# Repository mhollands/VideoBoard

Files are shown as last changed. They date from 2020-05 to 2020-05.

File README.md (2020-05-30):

# VideoBoard
Repo to hold files for the video board which was a prototype for the HP2VGA project

# Known Issues
Vsync and Hsync are swapped. C23 and C32 are unnecessary. Solution, use C23 and C32 footprints to swap the Vsync and Hsync inputs.





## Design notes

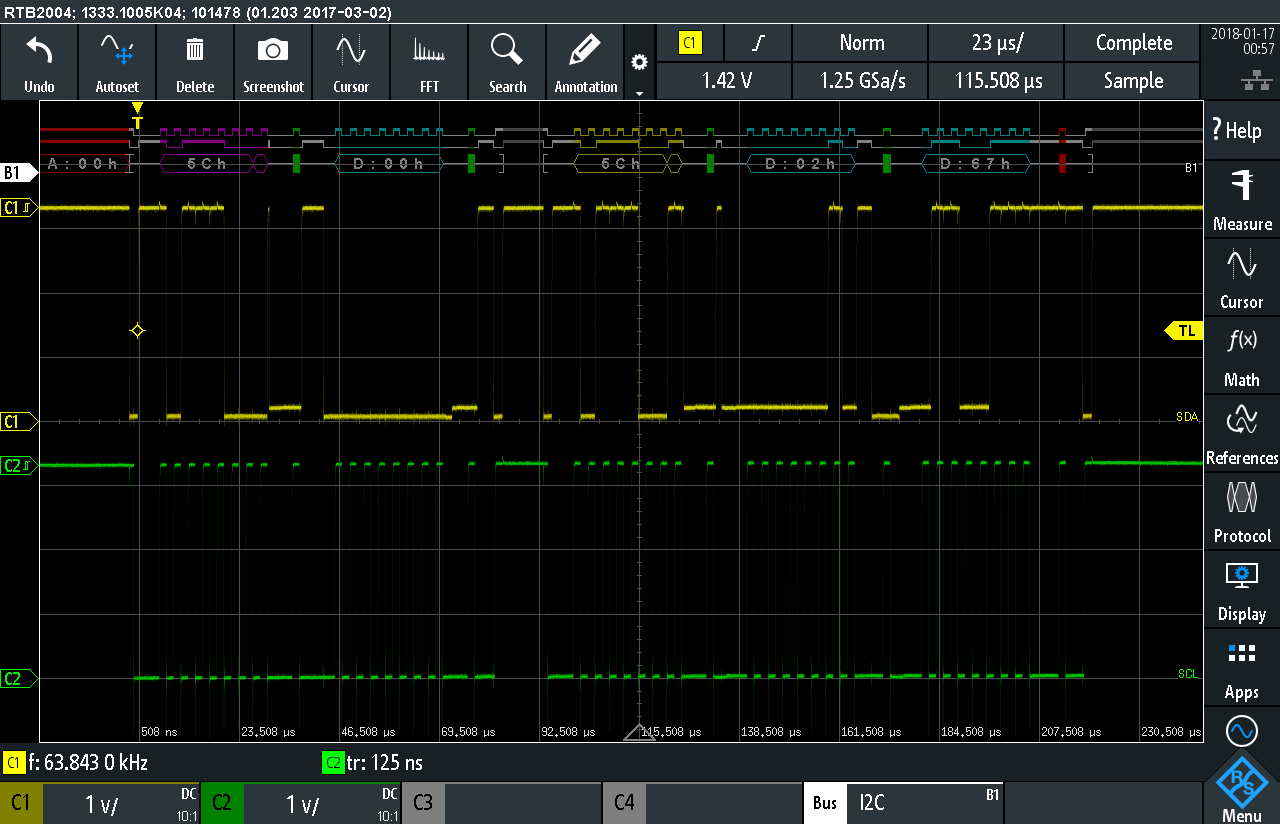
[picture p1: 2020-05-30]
Pictures/I2C.PNG

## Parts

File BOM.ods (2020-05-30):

Ref | Description | #Needed | Digikey#
CON1 | AVRISP Header Shrouded | 1 | 609-5122-ND | 2
IC1 | ATTiny87 | 1 | ATTINY87-SU-ND | 0
C2, C3, C36-C51, C21, C23, C32, C35 | 0603 0.1uF | 22 | - | 0
R8 | 0603 4k7 | 1 | - | 0
R6, R7, R10-R13, R15 | 0603 2k2 | 7 | 311-2.20KHRCT-ND | 100
P1 | 02x10 Header Shrouded | 1 | ED10524-ND | 1
L1-L6 | 0603 Ferrite 1A, 200 mOhm | 7 | MH1608-601YCT-ND | 10
R3 | 0603 75R | 1 | P75.0HCT-ND or 311-2667-1-ND | 10
R9 | 0603 330R | 1 | - | 0
C12, C26 | 0603 1nF | 2 | - | 0
U3 | Schmitt Trigger SOT-23-6 | 1 | 296-13012-1-ND | 2
C18-C20, C22, C25, C27-C31, C34 | 0603 10nF | 11 | 1276-1921-1-ND | 100
R14 | 0603 1k5 | 1 | - | 0
C17 | 0603 4.7nF | 1 | 1276-1098-1-ND | 10
P6, P7 | 02x06 Right Angle Header | 2 | S2111EC-06-ND | 2
C1, C4, C5 | 10uF, 2mm pitch, 5mm diameter | 3 | 1189-2322-ND | 3
U1 | 3V3 LDO, TO-220, Low thermal resistance | 1 | 497-1491-5-ND | 2
U2 | Adjustable LDO, DPAK | 1 | NCP1117DTAGOS-ND | 2
R2 | 0603 1k, 1% | 1 | - | 0
R1 | 0603 520R, 1% | 1 | 311-523HRCT-ND | 10
C6, C7, C10, C11, C15 | 0603 22uF | 5 | 1276-1193-1-ND | 10
C8, C9, C13, C14, C16 | 0603 1uF | 5 | - | 0
Heatsink | For U1 | 1 | A10761-ND | 2
U4 | TVP7002 | 1 | 296-22891-ND | 2

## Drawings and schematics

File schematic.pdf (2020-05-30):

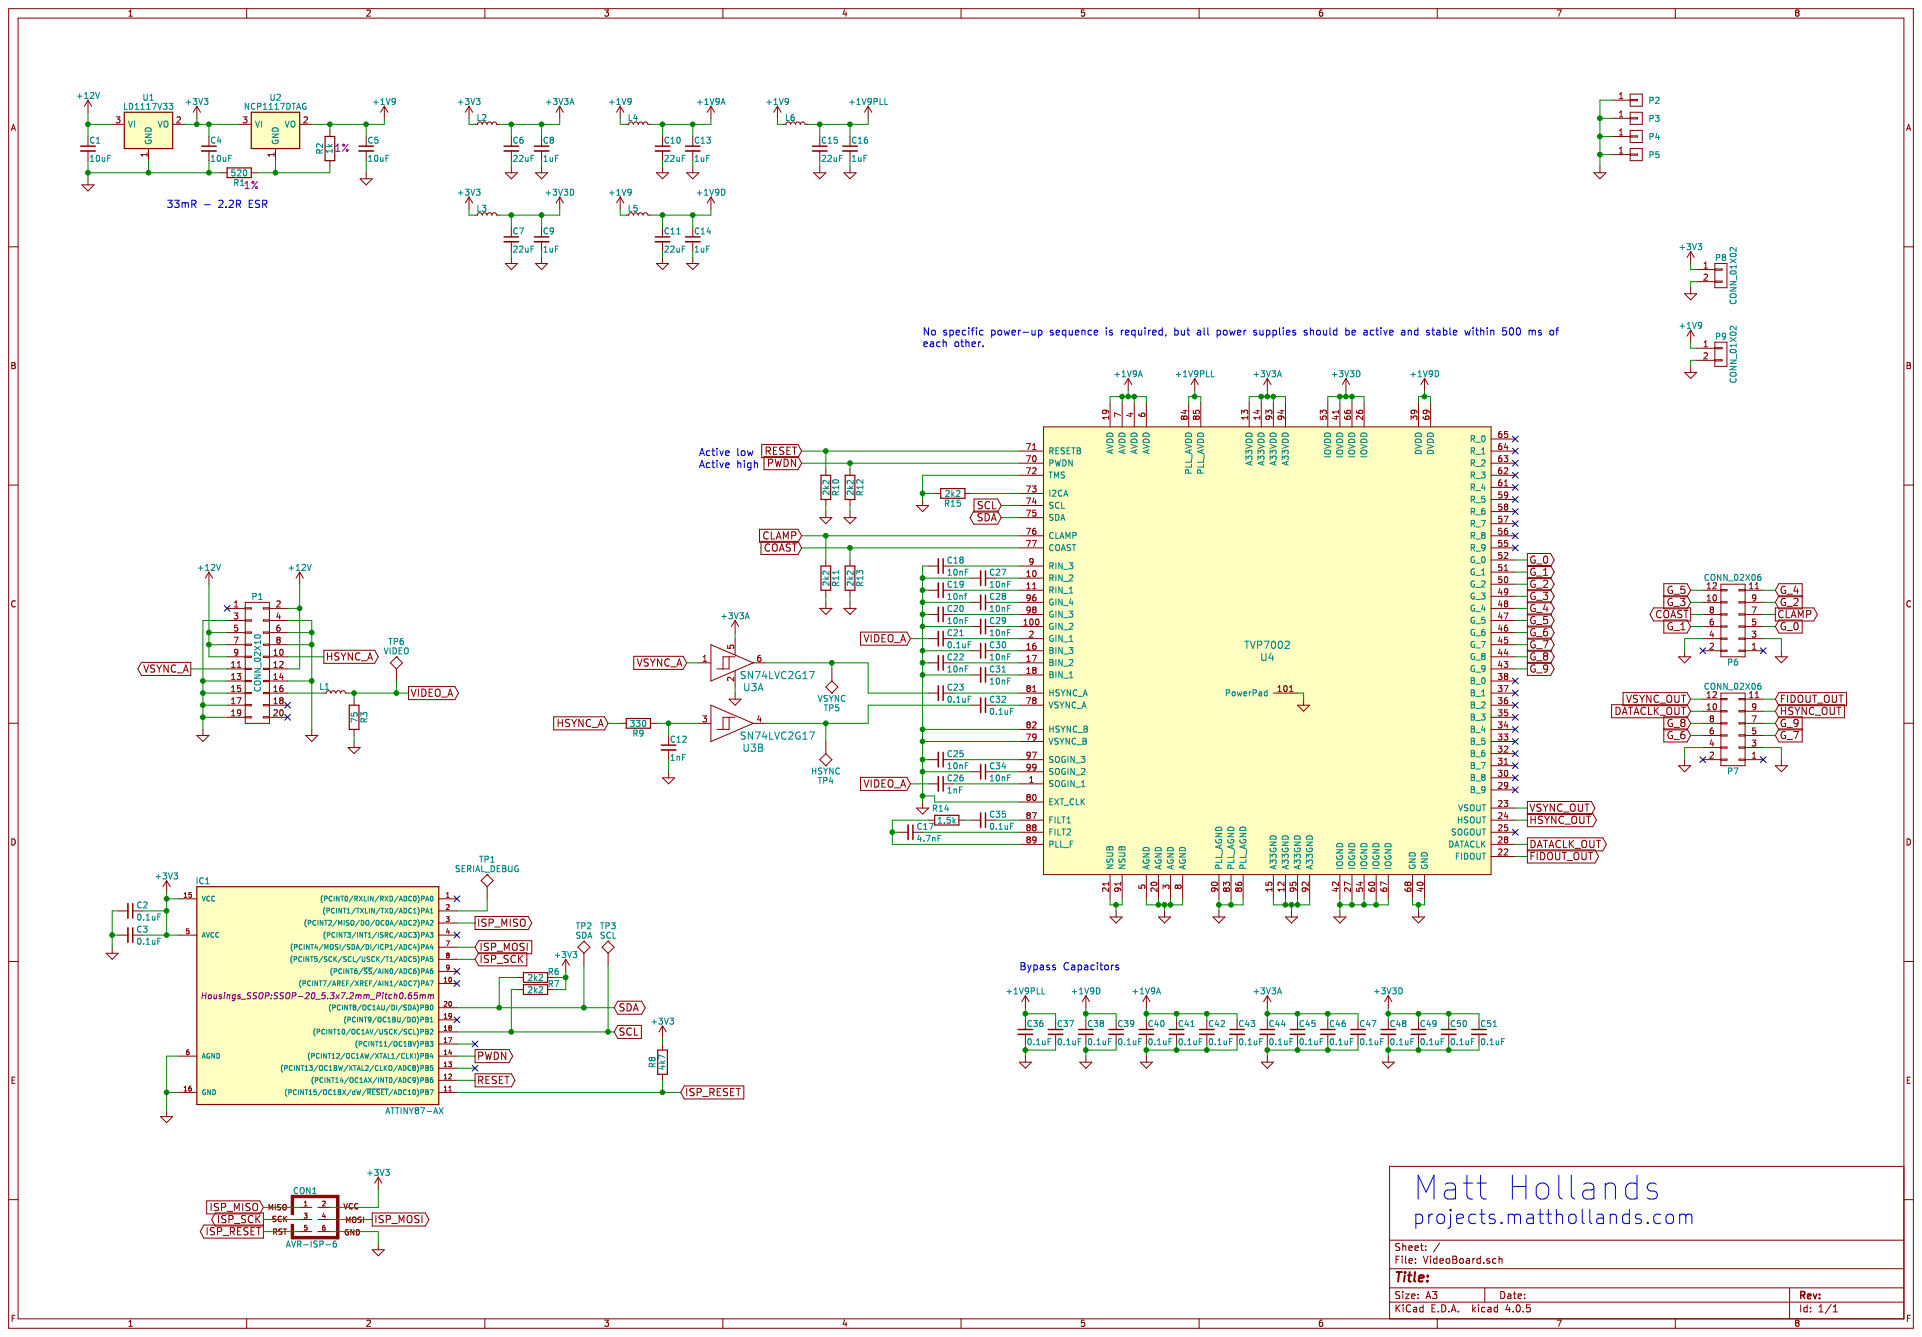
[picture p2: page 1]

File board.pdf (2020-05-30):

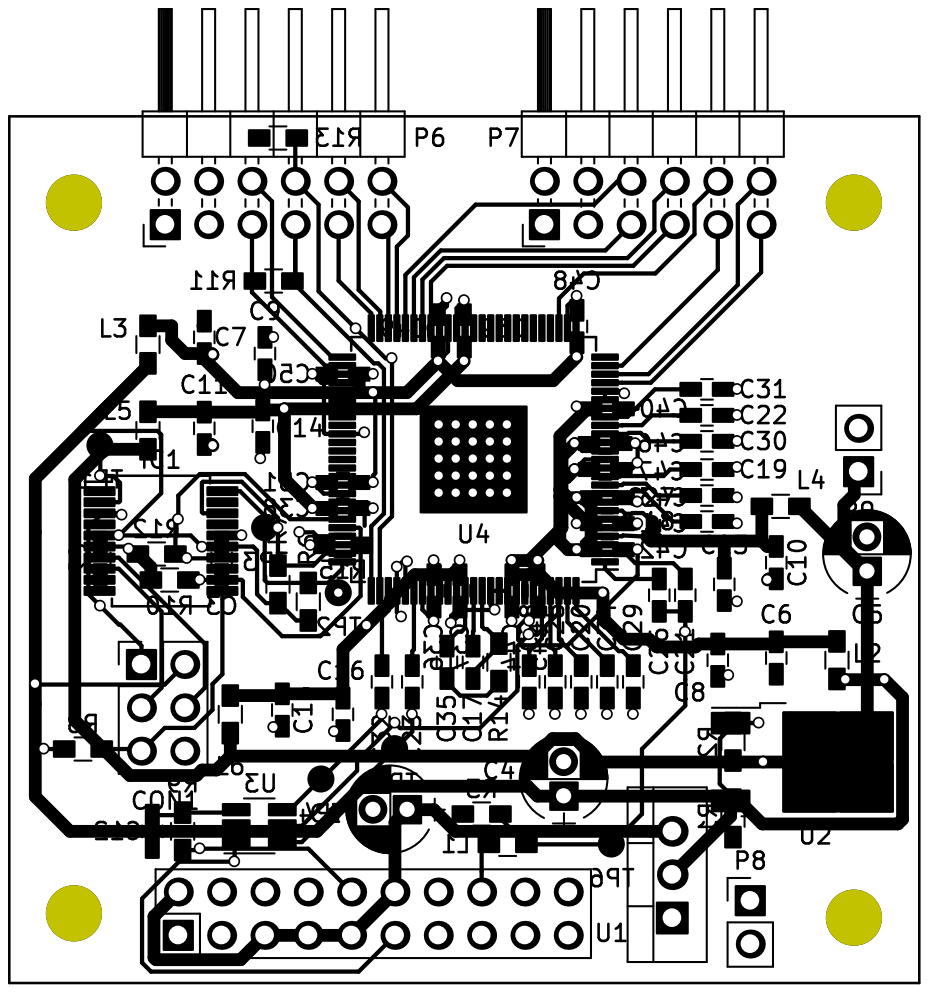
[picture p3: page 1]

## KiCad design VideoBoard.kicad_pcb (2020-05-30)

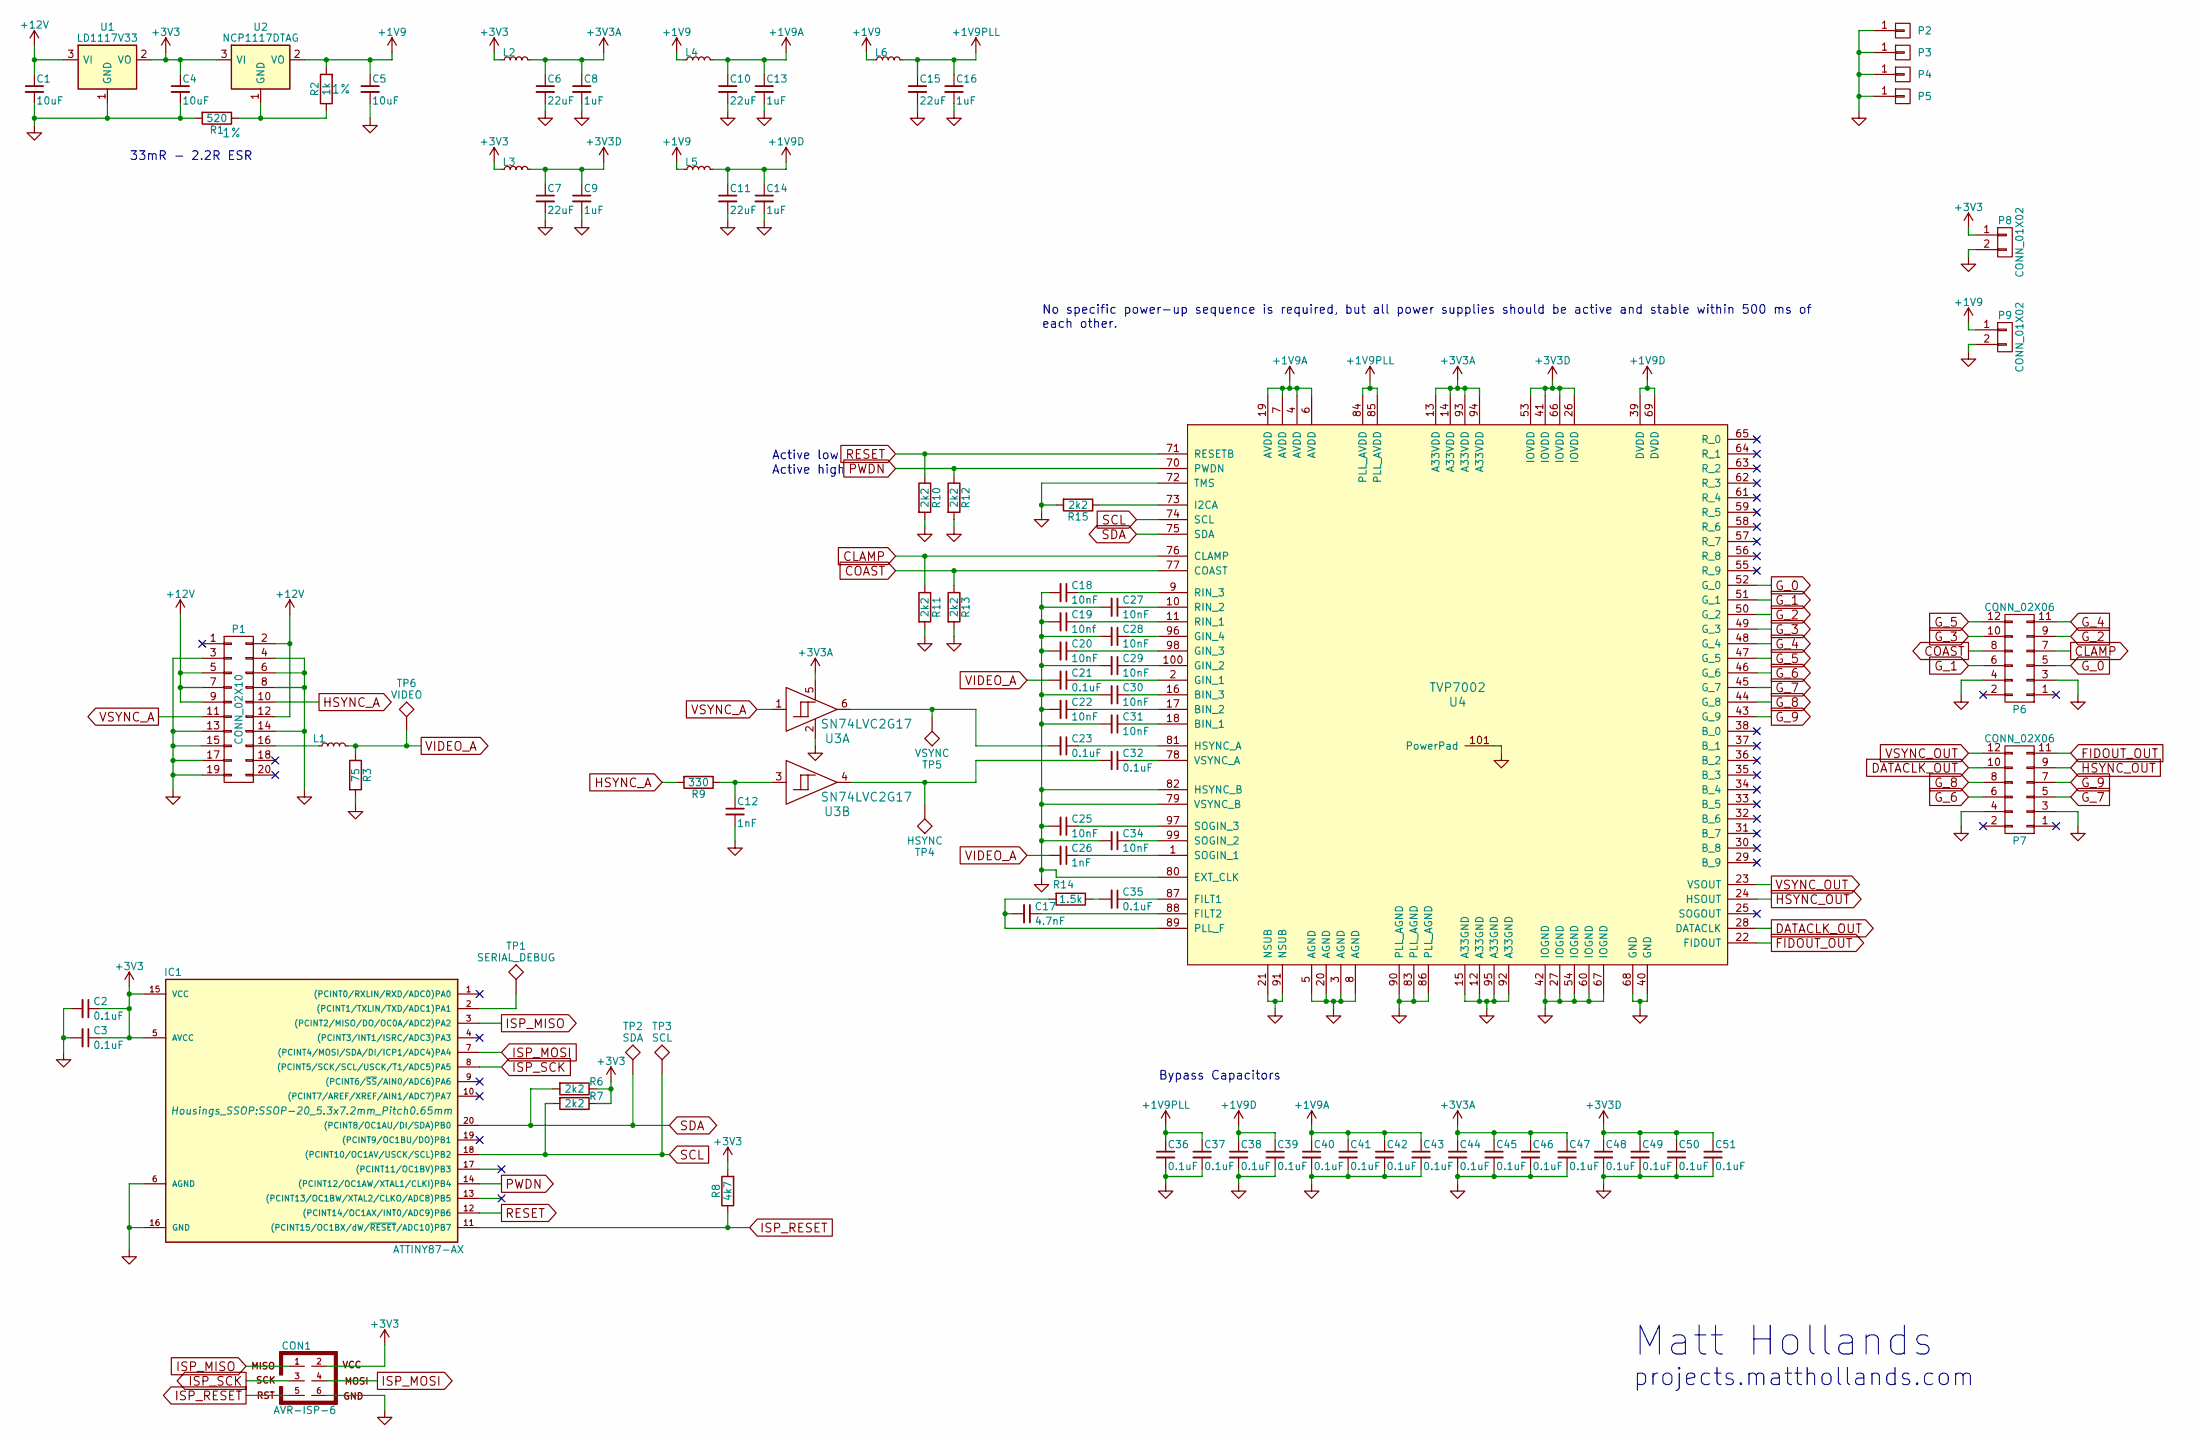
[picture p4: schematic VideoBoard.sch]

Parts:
C1, C4, C5: 10uF; CP_Radial_D5.0mm_P2.00mm; Digikey# 1189-2322-ND
C2, C3, C21, C23, C32, C35, C36, C37, C38, C39, C40, C41, C42, C43, C44, C45, C46, C47, C48, C49, C50, C51: 0.1uF; C_0603_HandSoldering
C6, C7, C10, C11, C15: 22uF; C_0603_HandSoldering
C8, C9, C13, C14, C16: 1uF; C_0603_HandSoldering
C12, C26: 1nF; C_0603_HandSoldering
C17: 4.7nF; C_0603_HandSoldering
C18, C20, C22, C25, C27, C28, C29, C30, C31, C34: 10nF; C_0603_HandSoldering
C19: 10nf; C_0603_HandSoldering
CON1: AVR-ISP-6; Pin_Header_Straight_2x03_Pitch2.54mm; Digikey# 609-5122-ND
IC1: ATTINY87-AX; SSOP-20_5.3x7.2mm_Pitch0.65mm
L1: L_Small; R_0603_HandSoldering
L2, L3, L4, L5, L6: L_Small; R_0603_HandSoldering; Digikey# MH1608-601YCT-ND
P1: CONN_02X10; Pin_Header_Straight_2x10_Pitch2.54mm
P2, P3, P4, P5: CONN_01X01; MountingHole_3.2mm_M3
P6, P7: CONN_02X06; Pin_Header_Angled_2x06_Pitch2.54mm
P8, P9: CONN_01X02; Pin_Header_Straight_1x02_Pitch2.54mm
R1: 520; R_0603_HandSoldering; Tolerance 1%
R2: 1k; R_0603_HandSoldering; Tolerance 1%
R3: 75; R_0603_HandSoldering
R6, R7, R10, R11, R12, R13, R15: 2k2; R_0603_HandSoldering
R8: 4k7; R_0603_HandSoldering
R9: 330; R_0603_HandSoldering
R14: 1.5k; R_0603_HandSoldering
TP1: SERIAL_DEBUG; Measurement_Point_Round-SMD-Pad_Small
TP2: SDA; Measurement_Point_Round-SMD-Pad_Small
TP3: SCL; Measurement_Point_Round-SMD-Pad_Small
TP4: HSYNC; Measurement_Point_Round-SMD-Pad_Small
TP5: VSYNC; Measurement_Point_Round-SMD-Pad_Small
TP6: VIDEO; Measurement_Point_Round-SMD-Pad_Small
U1: LD1117V33; TO-220_Vertical; Digikey# 497-1491-5-ND
U2: NCP1117DTAG; TO-252-2
U3: SN74LVC2G17; SOT-23-6_Handsoldering
U4: TVP7002; TQFP-100_14x14mm_Pitch0.5mm-PowerPad; Digikey# 296-22891-ND

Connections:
+1V9: C5.1, L4.1, L5.1, L6.1, P9.1, R2.2, U2.2 (VO)
+1V9A: C10.1, C13.1, C40.1, C41.1, C42.1, C43.1, L4.2, U4.4 (AVDD), U4.6 (AVDD), U4.7 (AVDD), U4.19 (AVDD)
+1V9D: C11.1, C14.1, C38.1, C39.1, L5.2, U4.39 (DVDD), U4.69 (DVDD)
+1V9PLL: C15.1, C16.1, C36.1, C37.1, L6.2, U4.84 (PLL_AVDD), U4.85 (PLL_AVDD)
+3V3: C2.1, C3.1, C4.1, CON1.2, IC1.5 (AVCC), IC1.15 (VCC), L2.1, L3.1, P8.1, R6.1, R7.1, R8.2, U1.2 (VO), U2.3 (VI)
+3V3A: C6.1, C8.1, C44.1, C45.1, C46.1, C47.1, L2.2, U3.5, U4.13 (A33VDD), U4.14 (A33VDD), U4.93 (A33VDD), U4.94 (A33VDD)
+3V3D: C7.1, C9.1, C48.1, C49.1, C50.1, C51.1, L3.2, U4.26 (IOVDD), U4.41 (IOVDD), U4.53 (IOVDD), U4.66 (IOVDD)
+12V: C1.1, P1.2, P1.5, P1.7, P1.9, P1.12, U1.3 (VI)
CLAMP: P6.7, R11.1, U4.76 (CLAMP)
COAST: P6.8, R13.1, U4.77 (COAST)
DATACLK_OUT: P7.10, U4.28 (DATACLK)
FIDOUT_OUT: P7.11, U4.22 (FIDOUT)
GND: C1.2, C2.2, C3.2, C4.2, C5.2, C6.2, C7.2, C8.2, C9.2, C10.2, C11.2, C12.2, C13.2, C14.2, C15.2, C16.2, C18.2, C19.2, C20.2, C22.2, C25.2, C27.2, C28.2, C29.2, C30.2, C31.2, C34.2, C36.2, C37.2, C38.2, C39.2, C40.2, C41.2, C42.2, C43.2, C44.2, C45.2, C46.2, C47.2, C48.2, C49.2, C50.2, C51.2, CON1.6, IC1.6 (AGND), IC1.16 (GND), P1.3, P1.4, P1.6, P1.8, P1.13, P1.14, P1.15, P1.17, P1.19, P2.1, P3.1, P4.1, P5.1, P6.3, P6.4, P7.3, P7.4, P8.2, P9.2, R1.2, R3.2, R10.2, R11.2, R12.2, R13.2, R15.2, U1.1 (GND), U3.2, U4.3 (AGND), U4.5 (AGND), U4.8 (AGND), U4.12 (A33GND), U4.15 (A33GND), U4.20 (AGND), U4.21 (NSUB), U4.27 (IOGND), U4.40 (GND), U4.42 (IOGND), U4.54 (IOGND), U4.60 (IOGND), U4.67 (IOGND), U4.68 (GND), U4.72 (TMS), U4.79 (VSYNC_B), U4.80 (EXT_CLK), U4.82 (HSYNC_B), U4.83 (PLL_AGND), U4.86 (PLL_AGND), U4.90 (PLL_AGND), U4.91 (NSUB), U4.92 (A33GND), U4.95 (A33GND), U4.101 (PowerPad)
G_0: P6.5, U4.52 (G_0)
G_1: P6.6, U4.51 (G_1)
G_2: P6.9, U4.50 (G_2)
G_3: P6.10, U4.49 (G_3)
G_4: P6.11, U4.48 (G_4)
G_5: P6.12, U4.47 (G_5)
G_6: P7.6, U4.46 (G_6)
G_7: P7.5, U4.45 (G_7)
G_8: P7.8, U4.44 (G_8)
G_9: P7.7, U4.43 (G_9)
HSYNC_A: P1.10, R9.2
HSYNC_OUT: P7.9, U4.24 (HSOUT)
ISP_MISO: CON1.1, IC1.3 ((PCINT2/MISO/DO/OC0A/ADC2)PA2)
ISP_MOSI: CON1.4, IC1.7 ((PCINT4/MOSI/SDA/DI/ICP1/ADC4)PA4)
ISP_RESET: CON1.5, IC1.11 ((PCINT15/OC1BX/dW/~RESET~/ADC10)PB7), R8.1
ISP_SCK: CON1.3, IC1.8 ((PCINT5/SCK/SCL/USCK/T1/ADC5)PA5)
unnamed: C12.1, R9.1, U3.3
unnamed: C17.1, U4.88 (FILT2)
unnamed: C17.2, R14.2, U4.89 (PLL_F)
unnamed: C18.1, U4.9 (RIN_3)
unnamed: C19.1, U4.11 (RIN_1)
unnamed: C20.1, U4.98 (GIN_3)
unnamed: C21.1, U4.2 (GIN_1)
unnamed: C22.1, U4.17 (BIN_2)
unnamed: C23.1, U4.81 (HSYNC_A)
unnamed: C23.2, TP5.1, U3.6
unnamed: C25.1, U4.97 (SOGIN_3)
unnamed: C26.1, U4.1 (SOGIN_1)
unnamed: C27.1, U4.10 (RIN_2)
unnamed: C28.1, U4.96 (GIN_4)
unnamed: C29.1, U4.100 (GIN_2)
unnamed: C30.1, U4.16 (BIN_3)
unnamed: C31.1, U4.18 (BIN_1)
unnamed: C32.1, U4.78 (VSYNC_A)
unnamed: C32.2, TP4.1, U3.4
unnamed: C34.1, U4.99 (SOGIN_2)
unnamed: C35.1, U4.87 (FILT1)
unnamed: C35.2, R14.1
unnamed: IC1.2 ((PCINT1/TXLIN/TXD/ADC1)PA1), TP1.1
unnamed: L1.1, P1.16
unnamed: R1.1, R2.1, U2.1 (GND)
unnamed: R15.1, U4.73 (I2CA)
PWDN: IC1.14 ((PCINT12/OC1AW/XTAL1/CLKI)PB4), R12.1, U4.70 (PWDN)
RESET: IC1.12 ((PCINT14/OC1AX/INT0/ADC9)PB6), R10.1, U4.71 (RESETB)
SCL: IC1.18 ((PCINT10/OC1AV/USCK/SCL)PB2), R7.2, TP3.1, U4.74 (SCL)
SDA: IC1.20 ((PCINT8/OC1AU/DI/SDA)PB0), R6.2, TP2.1, U4.75 (SDA)
VIDEO_A: C21.2, C26.2, L1.2, R3.1, TP6.1
VSYNC_A: P1.11, U3.1
VSYNC_OUT: P7.12, U4.23 (VSOUT)

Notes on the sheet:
No specific power-up sequence is required, but all power supplies should be active and stable within 500 ms of each other.
Bypass Capacitors
Active low
Active high
33mR - 2.2R ESR
Matt Hollands
projects.matthollands.com

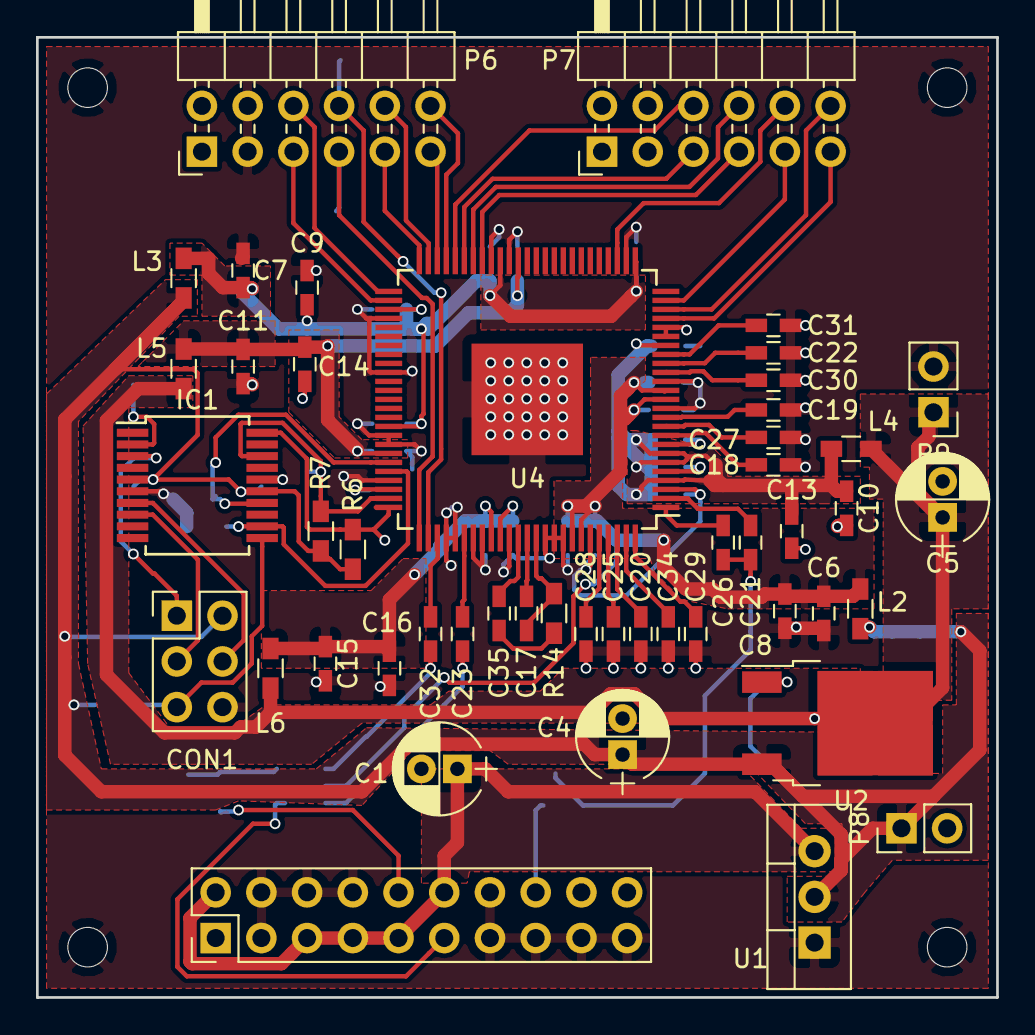
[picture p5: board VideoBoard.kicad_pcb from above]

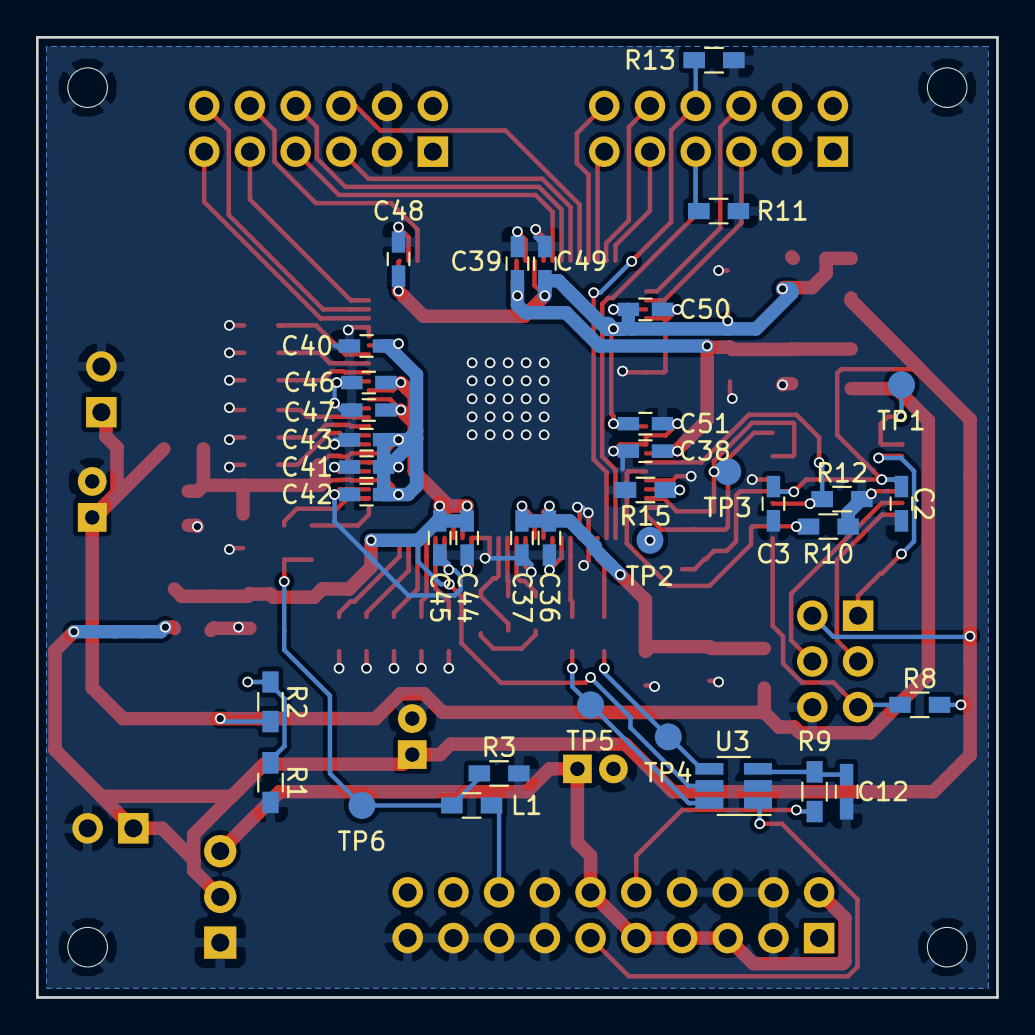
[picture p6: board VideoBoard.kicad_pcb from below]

Board: 2 copper layers, 53.3 x 53.3 mm, 89 parts (37 on the bottom side), 62 nets.

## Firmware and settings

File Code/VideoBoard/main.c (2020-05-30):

/*
 * VideoBoard.c
 *
 * Created: 29/11/2017 21:52:00
 * Author : Matt
 */ 

#define F_CPU 8000000U

#include <avr/io.h>
#include <util/delay.h>
//#include "usi_i2c_master.h"
#include <avr/interrupt.h>
#include "usiTwiMaster.h"

#define TVP_W 0xB8
#define TVP_R 0xB9
#define TVP_CHIP_REV 0x00
#define TVP_HPLL_DIV_MSB 0x01
#define TVP_HPLL_DIV_LSB 0x02
#define TVP_HPLL_CTRL 0x03
#define TVP_HPLL_PHASE 0x04
#define TVP_CLAMP_START 0x05
#define TVP_CLAMP_WIDTH 0x06
#define TVP_GREEN_FINE_OFFSET 0x0C
#define TVP_SYNC_CTRL1 0x0E
#define TVP_HPLL_PRECOAST 0x12
#define TVP_SYNC_DETECT_STATUS 0x14
#define TVP_MISC_CTRL2 0x17
#define TVP_MISC_CTRL3 0x18
#define TVP_MISC_CTRL4 0x22
#define TVP_ALC_EN 0x26
#define TVP_POWER_CTRL 0x2B
#define TVP_SYNC_BYPASS 0x36
#define TVP_LPFl_STATUS 0x37
#define TVP_LPFh_STATUS 0x38
#define TVP_CPLl_STATUS 0x39
#define TVP_CPLh_STATUS 0x3A
#define TVP_HSYNC_WIDTH 0x3B
#define TVP_VSYNC_WIDTH 0x3C
#define TVP_1ST_COEF 0x4A

//800 pixels per line. hsync is 64. FP is 136. BP is 24.
//417 lines per frame. vsync is 3. FP is 25. BP is 11.
uint8_t reg_setting[66] = {	TVP_W, 0x00, 0x00, 0x64, 0x00, 0x20, 0x01, 0x06, 0x10, 0x51, 0x00, 0x90, 0x00, 0x40, 0x78, 0x80, 0x52, 0x2E, 0x5D, 0x20, 0x03, 0x03, 0x00, 0x04, 0x11, 
							0x12, 0x00, 0x00, 0xC2, 0x77, 0x07, 0x00, 0x10, 0x10, 0x10, 0x00, 0x06, 0x00, 0x00, 0x00, 0x00, 0x00, 0x53, 0x08, 0x07, 0x85, 0x50, 0x00, 
							0x80, 0x8c, 0x04, 0x18, 0x18, 0x60, 0x03, 0x10, 0x00, 0x00, 0x00, 0x00, 0x00, 0x00, 0x00, 0x03, 0x04, 0x0F};
	
//green fine gain
//hsync output width
//h-pll phase select
//green fine offset msbs
//output formatter
//blue and green course gain
//fine offset LSBs
//green course offset
//hsout output start
// ALC enable
//RGB Course clamp control helps remove hum
//vsync alignment

//sync detect status should be 100100XX of 0x90, 0x91, 0x92 or 0x93
//lines per frame status should be 0xA121 YES!
//clocks per line status should be 0x0401 hmmmm 0x111 or 273... variation is 6.5mhz clock?
//hsync width should be 0x14 or 0x15 but is 0x15 or 0x16, variation in clock?
//vsync width should be 0x03

int main(void)
{
	sei();
	_delay_ms(100); //(TVP must be held in reset for 5ms after power up)
	DDRB = 0x45;
	PORTB |= 0x05;
	PORTB |= 0x40; //Bring TVP out of reset
	_delay_ms(100); //No I2C traffic for 1us after reset is released

	usiTwiMasterInitialize();
	/*
	uint8_t msg_w_sync_control1[3] = {TVP_W,TVP_SYNC_CTRL1, 0x52}; //prefer hsync to sog, derive vsync from vsync pin
	uint8_t msg_w_sync_bypass[3] = {TVP_W,TVP_SYNC_BYPASS, 0x02}; //bypass vsync
	uint8_t msg_w_misc_ctrl2[3] = {TVP_W,TVP_MISC_CTRL2, 0x02}; //enable outputs
	uint8_t msg_w_misc_ctrl3[3] = {TVP_W,TVP_MISC_CTRL3, 0x10}; //enable csc convertion outputs
	uint8_t msg_w_misc_ctrl4[3] = {TVP_W,TVP_MISC_CTRL4, 0x02}; //Disable macrovision and choose vs select
	uint8_t msg_w_hpll_divider[4] = {TVP_W,TVP_HPLL_DIV_MSB, 0x69, 0x80}; //set the pll divider value
	uint8_t msg_w_clamp[4] = {TVP_W,TVP_CLAMP_START, 0x06, 0x10}; //set the clamp length and start
	uint8_t msg_w_green_fine_offset[3] = {TVP_W,TVP_GREEN_FINE_OFFSET, 0x83}; //set the green offset to 1LSB
	uint8_t msg_w_hpll_ctrl[3] = {TVP_W,TVP_HPLL_CTRL, 0xA0}; //Set VCO and Charge Pump current to recommended settings for 1280x1024
	uint8_t msg_w_hpll_phase[3] = {TVP_W,TVP_HPLL_PHASE, 0x00}; //Set Hpll phase to 0
	uint8_t msg_w_hpll_precoast[3] = {TVP_W,TVP_HPLL_PRECOAST, 0x01}; //Set precoast to 13
	uint8_t msg_w_pwr_ctrl[3] = {TVP_W,TVP_POWER_CTRL, 0x40}; //power down SOG
	uint8_t msg_w_alc_en[3] = {TVP_W,TVP_ALC_EN, 0x00}; //disable ALC
	uint8_t msg_w_set_scs[4] = {TVP_W,TVP_1ST_COEF, 0x00, 0x00}; //disable ALC
		
	uint8_t msg_r_sync_status[4] = {TVP_W,TVP_SYNC_DETECT_STATUS,TVP_R, 0xFF};
	uint8_t msg_r_per[7] = {TVP_W,TVP_LPFl_STATUS,TVP_R, 0xFF,0xFF, 0xFF, 0xFF};
	uint8_t msg_r_sync_width[5] = {TVP_W,TVP_HSYNC_WIDTH,TVP_R, 0xFF, 0xFF};	
		*/
	uint8_t msg_r_everything[95];
	msg_r_everything[0] = TVP_W;
	msg_r_everything[1] = 0x00;
	msg_r_everything[2] = TVP_R;
	
	for(int i = 3; i < 96; i++)
	{
		msg_r_everything[i] = 0xff;
	}
	
	/*	
	//usiTwiStartTransceiverWithData(msg_w_sync_control1, 3);
	//usiTwiStartTransceiverWithData(msg_w_sync_bypass, 3);
	usiTwiStartTransceiverWithData(msg_w_misc_ctrl2, 3);
	usiTwiStartTransceiverWithData(msg_w_misc_ctrl4, 3);
	usiTwiStartTransceiverWithData(msg_w_hpll_divider, 4);
	usiTwiStartTransceiverWithData(msg_w_clamp, 4);
	//usiTwiStartTransceiverWithData(msg_w_green_fine_offset, 3);
	usiTwiStartTransceiverWithData(msg_w_hpll_ctrl, 3);
	usiTwiStartTransceiverWithData(msg_w_hpll_phase, 3);
	usiTwiStartTransceiverWithData(msg_w_hpll_precoast, 3);
	usiTwiStartTransceiverWithData(msg_w_pwr_ctrl, 3);
	usiTwiStartTransceiverWithData(msg_w_alc_en, 3);
	//usiTwiStartTransceiverWithData(msg_w_misc_ctrl3, 3);
	//usiTwiStartTransceiverWithData(msg_w_set_scs, 4);
	*/
	usiTwiStartTransceiverWithData(reg_setting, 66);
	
    while (1) 
    {
		//usiTwiStartTransceiverWithData(msg_r_vsync_width, 2);
		//usiTwiStartTransceiverWithData(msg_r_vsync_width+2, 2);
		//usiTwiStartTransceiverWithData(msg_r_per, 2);
		//usiTwiStartTransceiverWithData(msg_r_per+2, 5);
		_delay_ms(5000);
		
			usiTwiStartTransceiverWithData(msg_r_everything, 2);
			usiTwiStartTransceiverWithData(msg_r_everything+2, 93);
    }
}

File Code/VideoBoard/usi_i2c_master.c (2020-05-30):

/*
 * usi_i2c_master.c
 *
 * Created: 14/01/2018 22:14:30
 *  Author: Matt
 */ 
#include <avr/io.h>
#include <avr/interrupt.h>
#include <stdint.h>

#define IDLE 0x00
#define START 0x01
#define BITTOBUS 0x02
#define BITFROMBUS 0x03
#define STOP 0x04

void _usi_i2c_set_bus(char, char);
void _usi_i2c_start();

int _usi_i2c_state;
int _usi_i2c_num_bits = 0;
uint32_t _usi_i2c_buffer = 0;
int count = 0;

char cycle_parity = 0;

void USI_I2C_Initialise(int scl_freq)
{
	USIDR = 0xFF;
	USIPP |= (0 << USIPOS); //Set USI pin position as PB0 and PB2
	USICR |= (0 << USIWM0)|(1 << USIWM1); //Set the USI to two-wire mode
	USICR |= (0 << USICS0)|(0 << USICS1); //Set USI clock source to be soft-ware (in reality, probably want timer0 as clock source)
	USISR |= (1 << USISIF); //Clear USI start condition interrupt flag which pulls SCL low
	
	TCCR0A |= (1 << WGM01) | (0 << WGM00); //Set Timer0 to CTC mode
	OCR0A = 100; //Set output compare value to 80
	TIMSK0 |= (1 << OCIE0A); //Enable output compare interrupt
	
	_usi_i2c_state = IDLE;
}

void USI_I2C_Single_Write(char addr, char val)
{
	//We can't do anything if we are busy
	if(_usi_i2c_state != IDLE)
	{
		return;
	}
	
	_usi_i2c_num_bits = 17;
	_usi_i2c_buffer = ((uint32_t)(addr | 0x01) << 24) | ((uint32_t)val << 15) | 0x00800000;
	USIDR = 0xFF;
	_usi_i2c_start();
}

void USI_I2C_Single_Read(char addr)
{
	
}

char USI_I2C_Single_Read_Blocking(char addr)
{
	return 0;
}

int USI_I2C_Busy()
{
	return _usi_i2c_state != IDLE;
}

ISR(TIMER0_COMPA_vect)
{
	cycle_parity = ~cycle_parity;
	//If it's halfway between clock edges and we are in BITTOBUS mode then we should shift onto the bus
	if(cycle_parity == 0xFF)
	{
		if(_usi_i2c_state == BITTOBUS)
		{
			_usi_i2c_set_bus(0, _usi_i2c_buffer >> 31); 
			_usi_i2c_buffer = (_usi_i2c_buffer << 1);
		}
		return;
	}
	
	switch(_usi_i2c_state)
	{
		case IDLE: //The timer shouldn't be running if we're in IDLE mode
			TCCR0B &= ~((1 << CS00) | (1 << CS01) | (1 << CS02));
			break;
		case START:
			count = 0;
			_usi_i2c_state = BITTOBUS; //Next state is loading a bit onto the bus (either by slave or master)
			_usi_i2c_set_bus(0, 1); //Lower clock
			USISR |= (1 << USISIF); //Clear the start-condition flag
			break;
		case BITTOBUS:
			//If we have sent all our bits
			if(count >= _usi_i2c_num_bits)
			{
				_usi_i2c_state = STOP;
				_usi_i2c_set_bus(1,0); //Raise SCL and lower SDA in preparation for a stop condition
				break;
			}
			count++;
			_usi_i2c_state = BITFROMBUS; //Next state is removing a bit from the bus (either by slave or master)
			USICR |= (1 << USITC); //Toggle clock (low to high)
			break;
		case BITFROMBUS:
			_usi_i2c_state = BITTOBUS;
			USICR |= (1 << USITC); //Toggle clock (high to low)
			break;
		case STOP:
			_usi_i2c_state = IDLE;
			_usi_i2c_set_bus(1,1);
			USIDR = 0xFF;
			break;
		default:	
			_usi_i2c_state = IDLE;
			TCCR0B &= ~((1 << CS00) | (1 << CS01) | (1 << CS02));
			break;
	}
}

void _usi_i2c_start()
{
	if(_usi_i2c_state != IDLE)
	{
		return;
	}
	
	TCCR0B |= (1 << CS00) | (0 << CS01) | (0 << CS02); //Set clock source to be system clock
	
	_usi_i2c_state = START;
	_usi_i2c_set_bus(1, 0);
}

void _usi_i2c_set_bus(char scl, char sda)
{
	PORTB = ((PORTB & 0b11111010) | (scl << 2) | (sda << 0));
}
